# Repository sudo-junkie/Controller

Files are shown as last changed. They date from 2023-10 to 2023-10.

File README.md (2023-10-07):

# Controller

KiCad 7 design files (schematic, PCB, gerber, BOM) for a replacement PCB for the UCOM USB game controller that introduces the following features:
- ESP32 based (WiFi + Bluetooth onboard) with external (IPEX) antenna
- SPI LCD Connector
- Micro SD Card slot 
- Single cell lithium battery charger
- USB C for programming/joystick
- Onboard accelerometer + gyroscope + magnetometer (MPU9250)
- 8 analog inputs (4 pressure-sensitive buttons + 2 joysticks)
- 8 digital inputs
- Toggle switch
- Infrared TX/RX 
- RGB LED

While this board has been designed to be dimensionally identical to the original PCB, a little 'hacking' on the part of the casing to make room for the USB connector, infrared transmitter/receiver and for the mounting of the toggle switch and external ESP32 antenna.

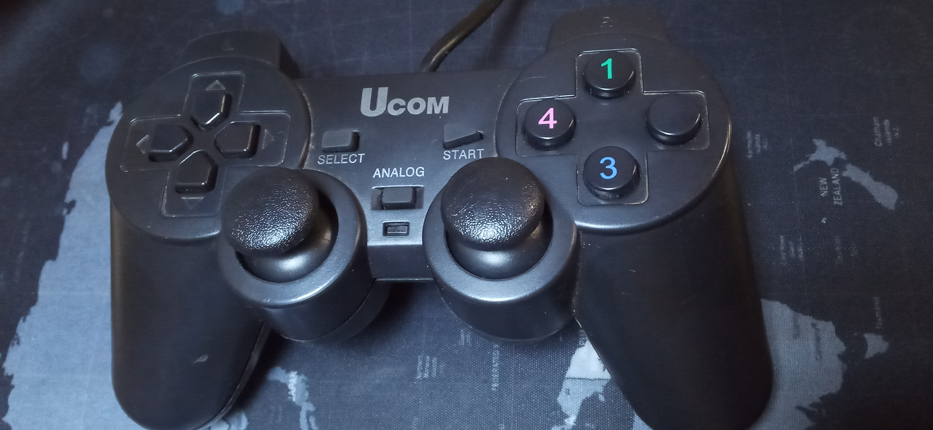
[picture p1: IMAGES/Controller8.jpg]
UCOM Controller


- Original

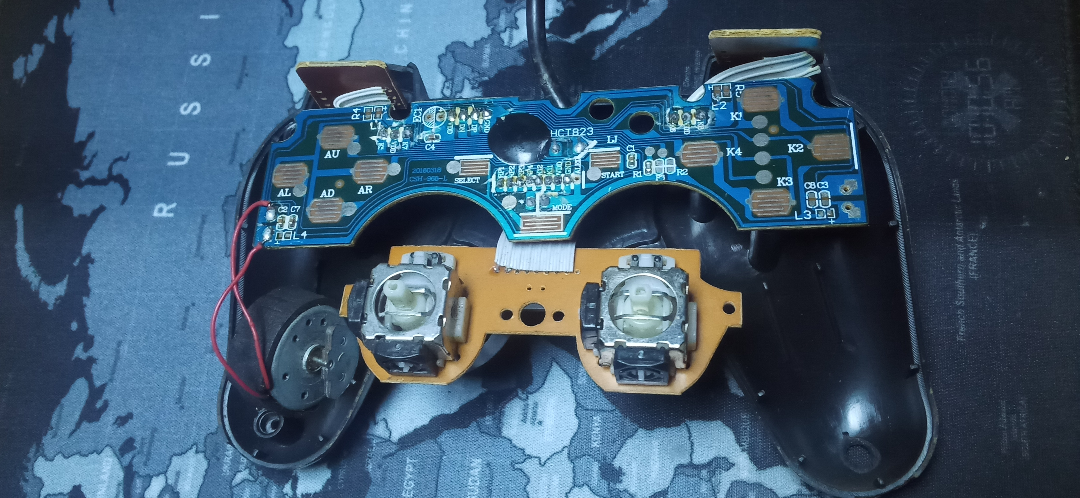
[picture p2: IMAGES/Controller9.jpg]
Controller Top

  
- Upgraded

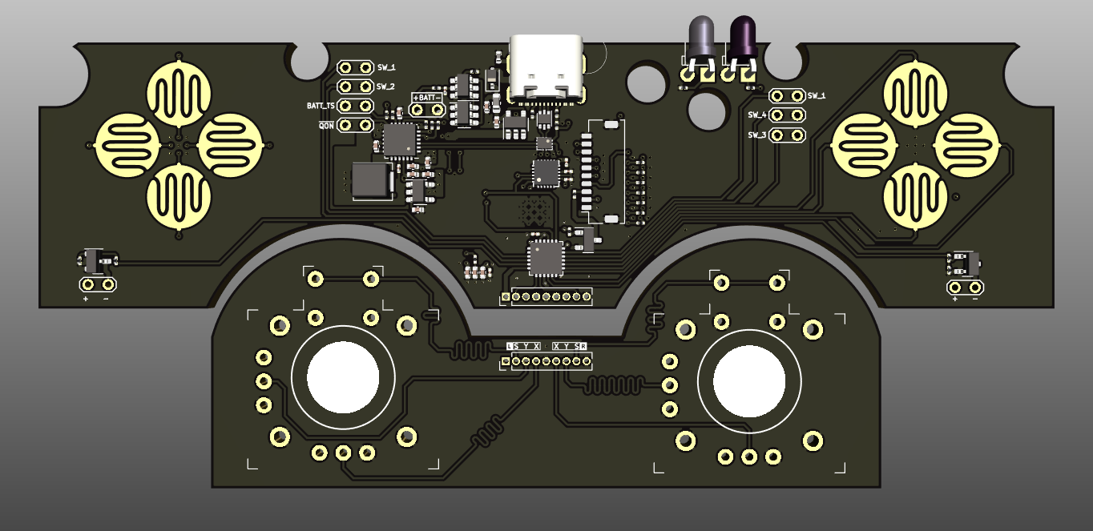
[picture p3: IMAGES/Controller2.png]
Controller Top


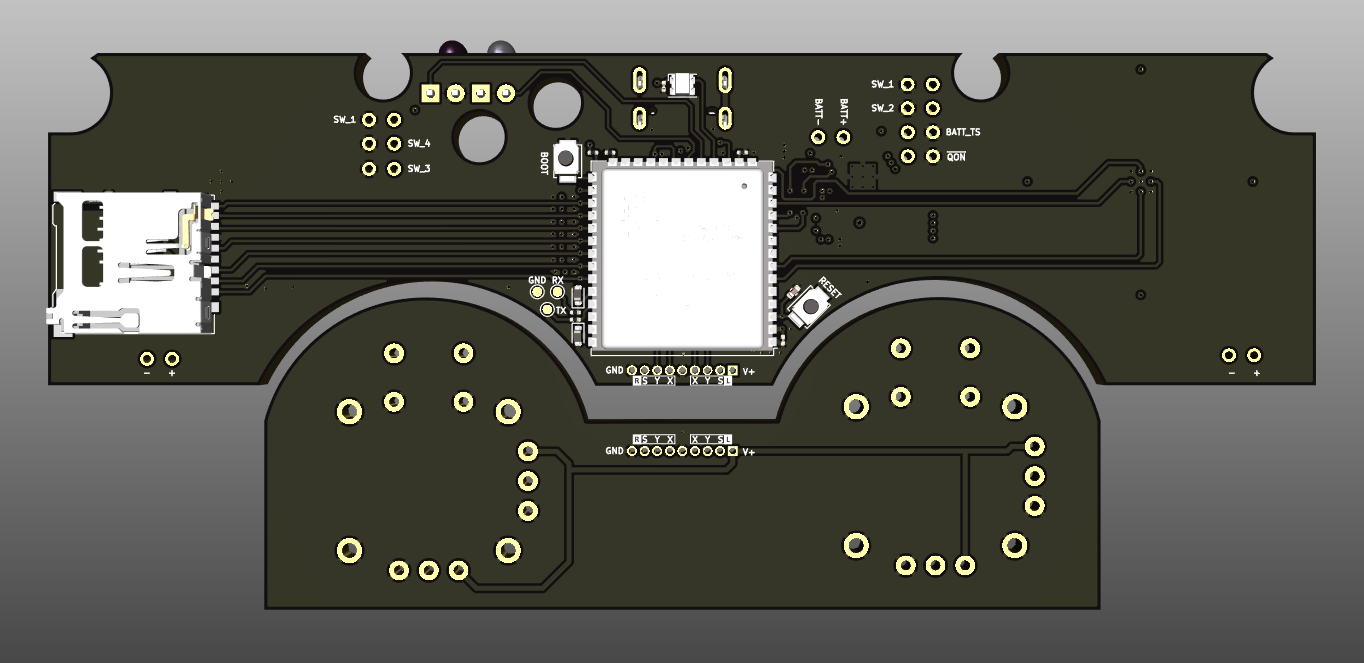
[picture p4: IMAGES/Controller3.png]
Controller Bottom


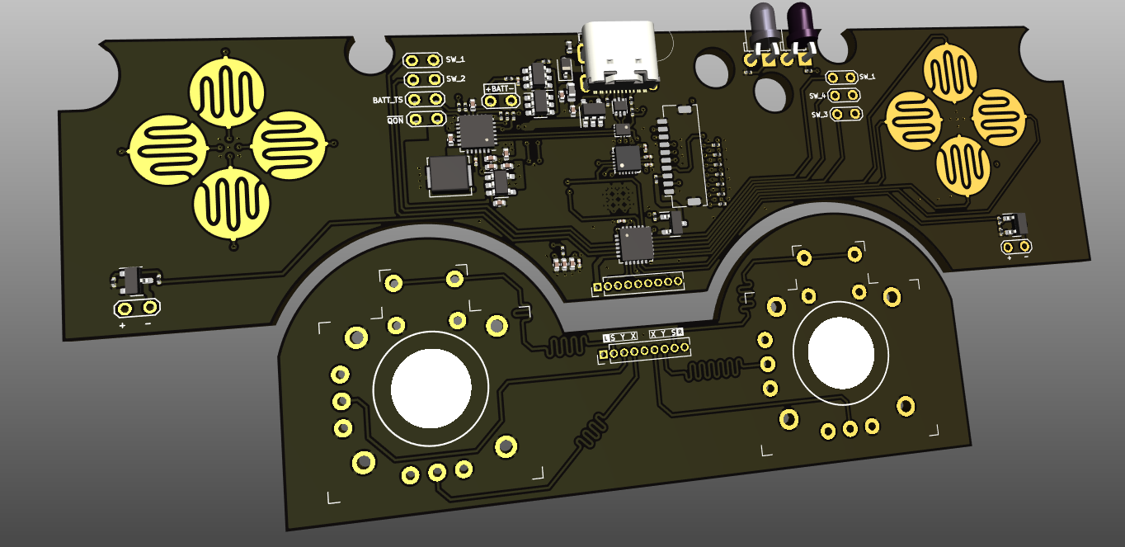
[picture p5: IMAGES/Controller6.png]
Controller Isometric


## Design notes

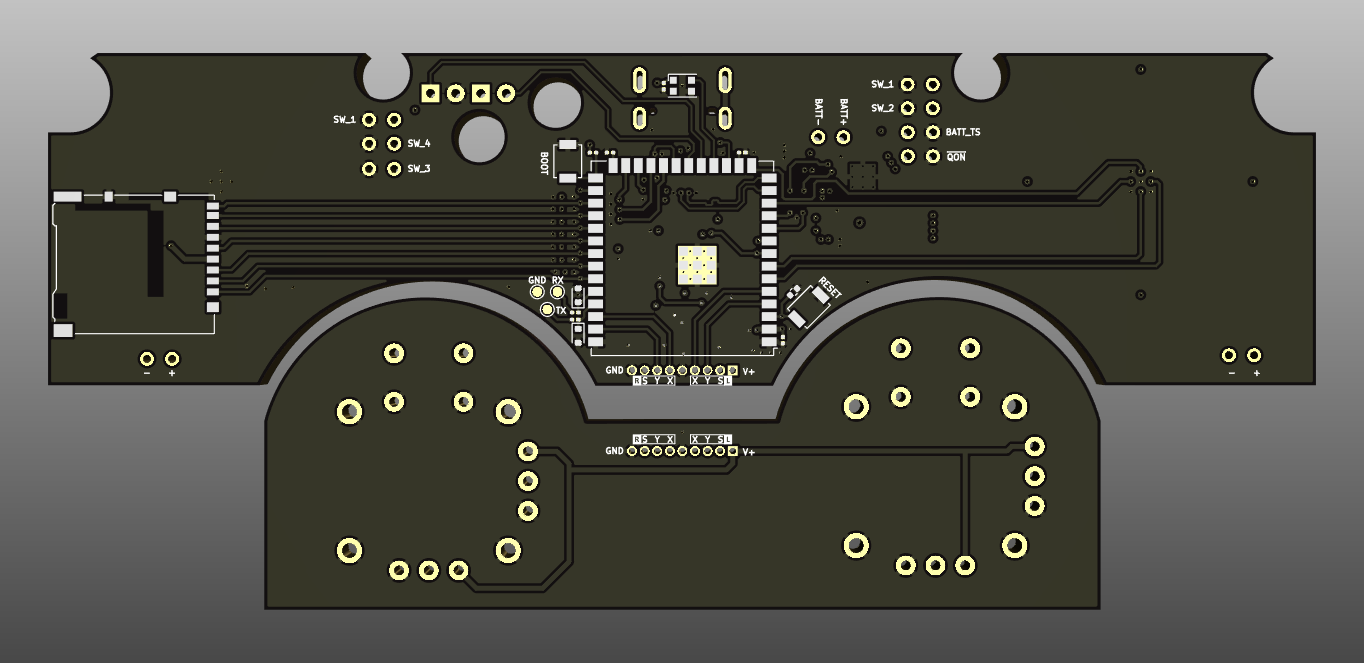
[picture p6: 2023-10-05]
IMAGES/Controller1.png

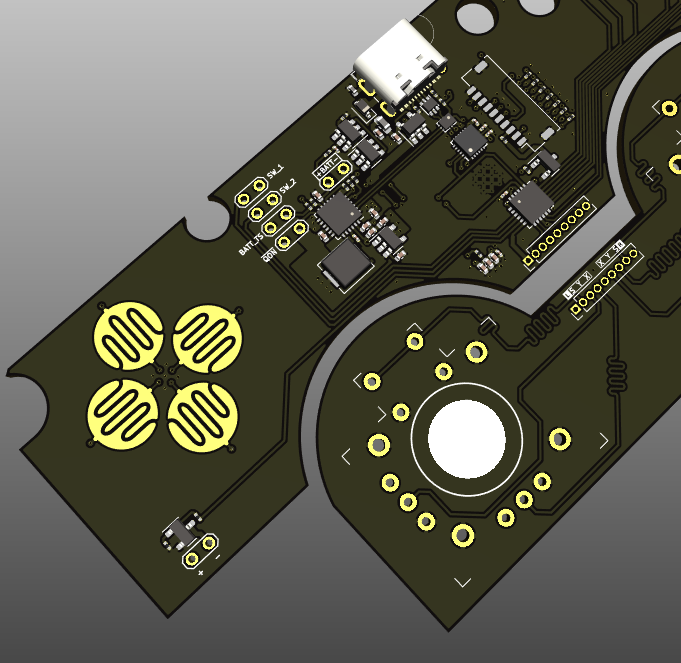
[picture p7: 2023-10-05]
IMAGES/Controller4.png

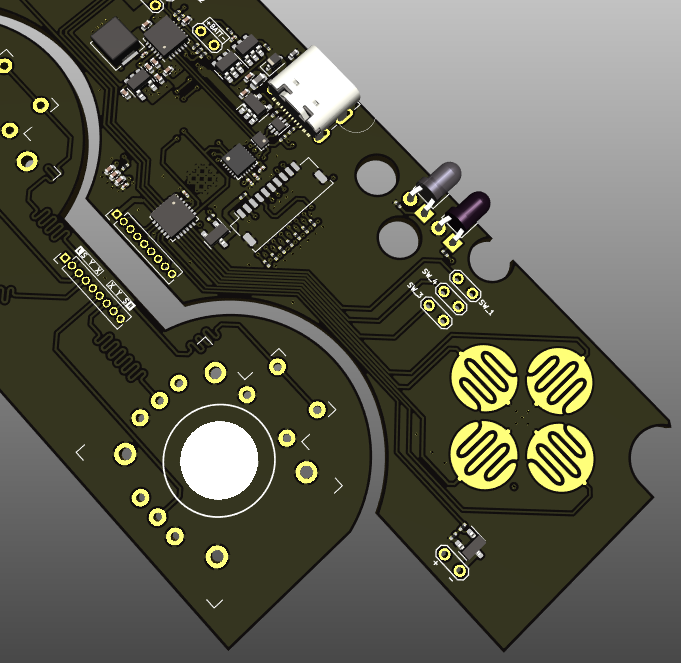
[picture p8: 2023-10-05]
IMAGES/Controller5.png

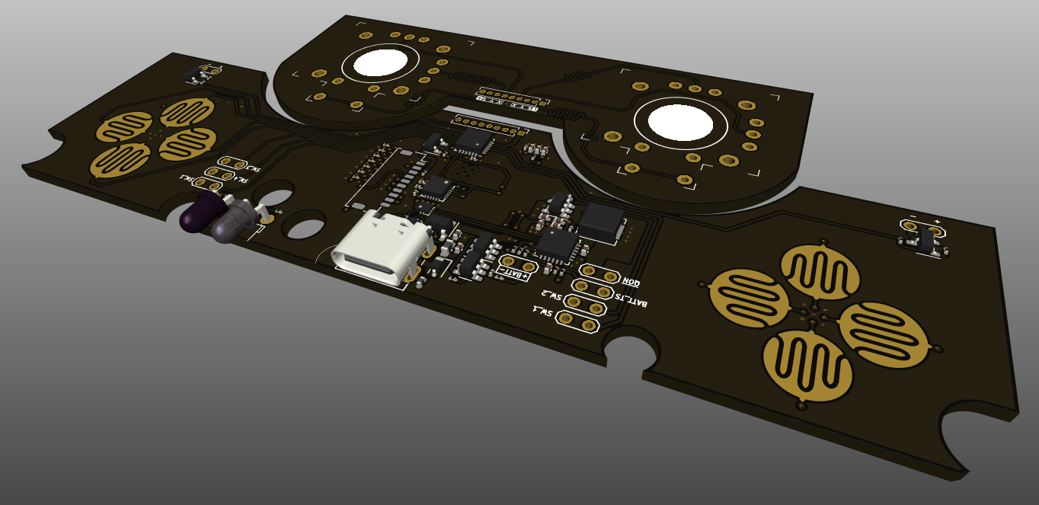
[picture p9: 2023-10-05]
IMAGES/Controller7.png

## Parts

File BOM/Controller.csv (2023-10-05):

Reference | Value | Footprint | JLCPCB # | MANUFACTURER | MPN | UNIT PRICE | VENDOR | Qty
C201, C202, C304, C307, C308, C403, C406 | 1u 10% 10V X5R | Capacitor_SMD:C_0402_1005Metric | C14445 | Samsung Electro-Mechanics | CL05A105KP5NNNC | 0.0019 | LCSC | 7
C301 | 10u 20% 16V X5R | Capacitor_SMD:C_0402_1005Metric | C315248 | Samsung Electro-Mechanics | CL05A106MP5NUNC | 0.0111 | LCSC | 1
C302, C303, C401, C402 | 10u 10% 10V X5R | Capacitor_SMD:C_0402_1005Metric | C962136 | Samsung Electro-Mechanics | CL10A106KO8NQNC | 0.0278 | LCSC | 4
C305 | 4u7 20% 16V X5R | Capacitor_SMD:C_0402_1005Metric | C318563 | Samsung Electro-Mechanics | CL05A475MO5NUNC | 0.0099 | LCSC | 1
C306, C404, C407, C502-C505 | 100n 10% 16V X5R | Capacitor_SMD:C_0201_0603Metric | C307380 | Samsung Electro-Mechanics | CL03A104KO3NNNC | 0.0018 | LCSC | 7
C309 | 47n 10% 16V X5R | Capacitor_SMD:C_0201_0603Metric | C7393833 | CCTC | TCC0201X5R473K160ZT | 0.0009 | LCSC | 1
C405, C501 | 10n 10% 10V X7R | Capacitor_SMD:C_0201_0603Metric | C526939 | YAGEO | CC0201JRX7R7BB103 | 0.0017 | LCSC | 2
D201 | 3A | Diode_SMD:D_SOD-323 | C133103 | STMicroelectronics | BAT60JFILM | 0.1038 | LCSC | 1
D401, D402 | 3V3 | Diode_SMD:D_SOD-523 | C209615 | ROHM Semicon | EDZVT2R3.3B | 0.0167 | LCSC | 2
D403 | WS2812B | LED_SMD:LED_WS2812B-2020_PLCC4_2.0x2.0mm | C5349955 | XINGLIGHT | XL-2020RGBC-WS2812B | 0.072 | LCSC | 1
D501 | IR204A | LED_THT:LED_D3.0mm_Horizontal_O1.27mm_Z2.0mm_IRGrey | C7470790 | TONYU | DY-IR204T-E12 | 0.041 | LCSC | 1
FB201 | 120R@100MHz 3A | Inductor_SMD:L_0603_1608Metric | C353920 | TAI-TECH | HCB1608KF-121T30 | 0.0035 | LCSC | 1
J101 | USB_C_Receptacle_USB2.0 | Connector_USB:USB_C_Receptacle_JAE_DX07S016JA1R1500 | C5187472 | SHOU HAN | TYPE-C 16P QTWT | 0.0662 | LCSC | 1
J501 | Micro_SD_Card | Connector_Card:microSD_HC_Hirose_DM3AT-SF-PEJM5 | C114218 | HRS(Hirose) | DM3AT-SF-PEJM5 | 1.1789 | LCSC | 1
J502 | Conn_LCD | Connector_JST:JST_SHL_SM10B-SHLS-TF_1x10-1MP_P1.00mm_Horizontal | C262716 | JUSHUO | AFA07-S10FCA-00 | 0.1068 | LCSC | 1
L101 | 1u | Inductor_SMD:L_0402_1005Metric | C84468 | Sunlord | SDFL1005Q1R0KTF | 0.0095 | LCSC | 1
L301 | 1u | Inductor_SMD:L_Sunlord_MWSA0402S | C7187305 | DMBJ | CXP0420-1ROM-AG(1uh) | 0.101 | LCSC | 1
Q501-Q503 | MMBT3904 | Package_TO_SOT_SMD:SOT-23 | C5184404 | HXY MOSFET | MMBT3904 | 0.0052 | LCSC | 3
Q504 | Q_Photo_NPN | LED_THT:LED_D3.0mm_Horizontal_O1.27mm_Z2.0mm_IRBlack | C7470722 | TONYU | DY-PT204B-A5 | 0.0477 | LCSC | 1
R201, R305-R308, R403-R406, R501-R507, R512, R513 | 10K 0.5% | Resistor_SMD:R_0201_0603Metric | C319932 | Viking Tech | AR01DTD1002 | 0.0068 | LCSC | 18
R202, R203, R303 | 5K1 0.5% | Resistor_SMD:R_0201_0603Metric | C319556 | Viking Tech | AR01DTD5101 | 0.0224 | LCSC | 3
R301 | 100R | Resistor_SMD:R_0201_0603Metric | C270366 | UNI-ROYAL(Uniroyal Elec) | 0201WMF1000TEE | 0.0007 | LCSC | 1
R302, R508-R511, R514, R515 | 1K | Resistor_SMD:R_0201_0603Metric | C270365 | UNI-ROYAL(Uniroyal Elec) | 0201WMF1001TEE | 0.0007 | LCSC | 7
R304 | 30K9 | Resistor_SMD:R_0201_0603Metric | C364366 | YAGEO | RC0201FR-0730K9L | 0.0004 | LCSC | 1
R401, R402 | 470R | Resistor_SMD:R_0201_0603Metric | C852285 | YAGEO | RT0201DRD07470RL | 0.0447 | LCSC | 2
SW301 | SW_PWR | TestPoint:TestPoint_2Pads_Pitch2.54mm_Drill0.8mm | C231329 | Omron Electronics | B3U-1000P | 0.1729 | LCSC | 1
SW401 | SW_RST | Button_Switch_SMD:SW_SPST_B3U-1000P | C231329 | Omron Electronics | B3U-1000P | 0.1729 | LCSC | 1
SW402 | SW_DWN | Button_Switch_SMD:SW_SPST_B3U-1000P | C231329 | Omron Electronics | B3U-1000P | 0.1729 | LCSC | 1
TH301 | 103AT | TestPoint:TestPoint_2Pads_Pitch2.54mm_Drill0.8mm | C123373 | Nanjing Shiheng Elec | MF52A103J3435 (A1) | 0.0288 | LCSC | 1
U201 | AP2171W | Package_TO_SOT_SMD:SOT-23-5 | C110466 | Diodes Incorporated | AP2171WG-7 | 0.1141 | LCSC | 1
U202 | PI3USB4000AZM | Package_DFN_QFN:UQFN-10_1.4x1.8mm_P0.4mm | C559586 | Diodes Incorporated | PI3USB4000AZMEX | 0.7223 | LCSC | 1
U203 | USBLC6-2P6 | Package_TO_SOT_SMD:SOT-666 | C5199178 | ElecSuper | USBLC6-2P6-ES | 0.0584 | LCSC | 1
U301 | DW01A | Package_TO_SOT_SMD:SOT-23-6 | C351410 | PUOLOP | DW01A | 0.0341 | LCSC | 1
U302 | 8205S | Package_TO_SOT_SMD:SOT-23-6 | C2762930 | JSMSEMI | 8205S | 0.0367 | LCSC | 1
U303 | TLV75733PDBV | Package_TO_SOT_SMD:SOT-23-5 | C485517 | Texas Instruments | TLV75733PDBVR | 0.1877 | LCSC | 1
U304 | BQ25611 | Package_DFN_QFN:WQFN-24-1EP_4x4mm_P0.5mm_EP2.6x2.6mm_ThermalVias | C2892871 | Texas Instruments | BQ25611DRTWR | 1.5735 | LCSC | 1
U401 | ESP32-S3-WROOM-1-N16R8 | RF_Module:ESP32-S3-WROOM-1U | C2980299 | Espressif Systems | ESP32-S3-MINI-1U-N8 | 5.2516 | LCSC | 1
U501 | MPU-9250 | Sensor_Motion:InvenSense_QFN-24_3x3mm_P0.4mm | C71459 | TDK InvenSense | MPU-9250 | 9.9178 | LCSC | 1
U503 | TCA9555RTWR | Package_DFN_QFN:WQFN-24-1EP_4x4mm_P0.5mm_EP2.45x2.45mm | C140277 | Texas Instruments | TCA9555RTWR | 1.4287 | LCSC | 1

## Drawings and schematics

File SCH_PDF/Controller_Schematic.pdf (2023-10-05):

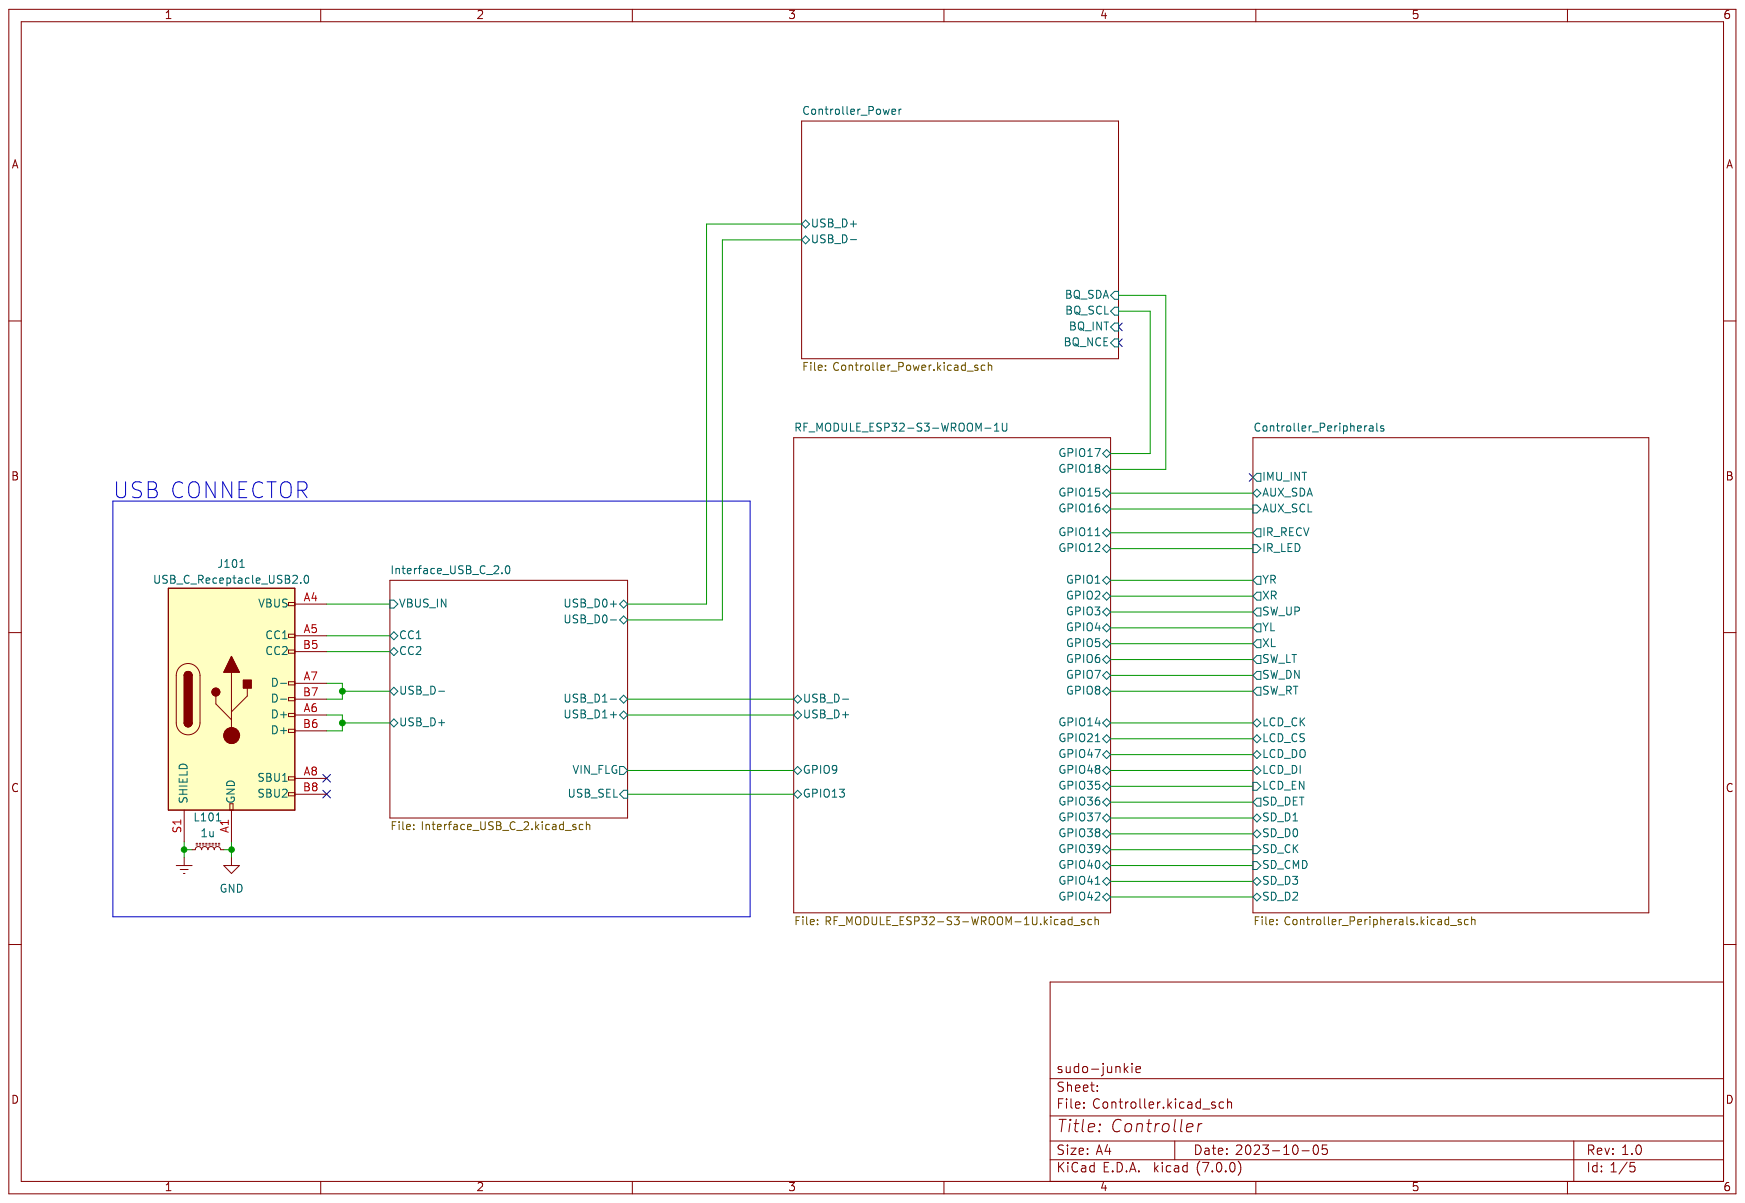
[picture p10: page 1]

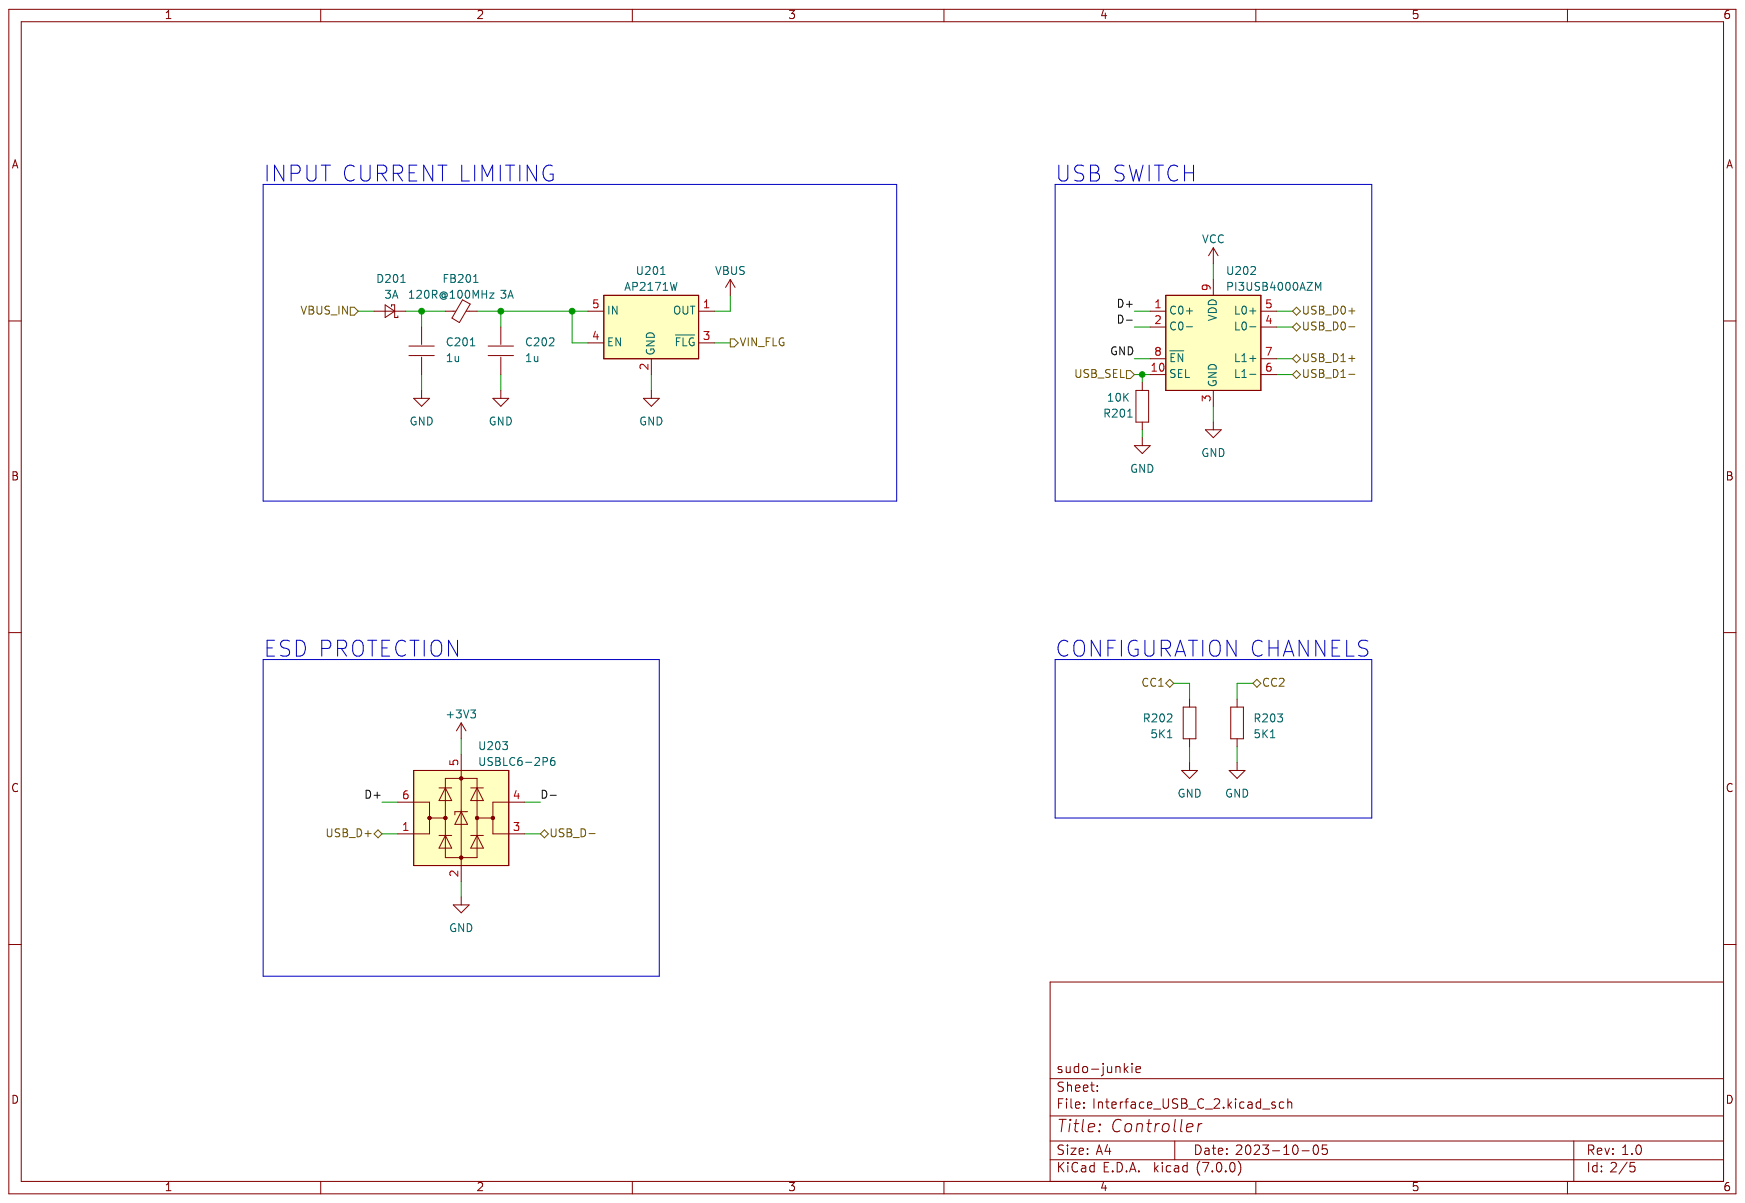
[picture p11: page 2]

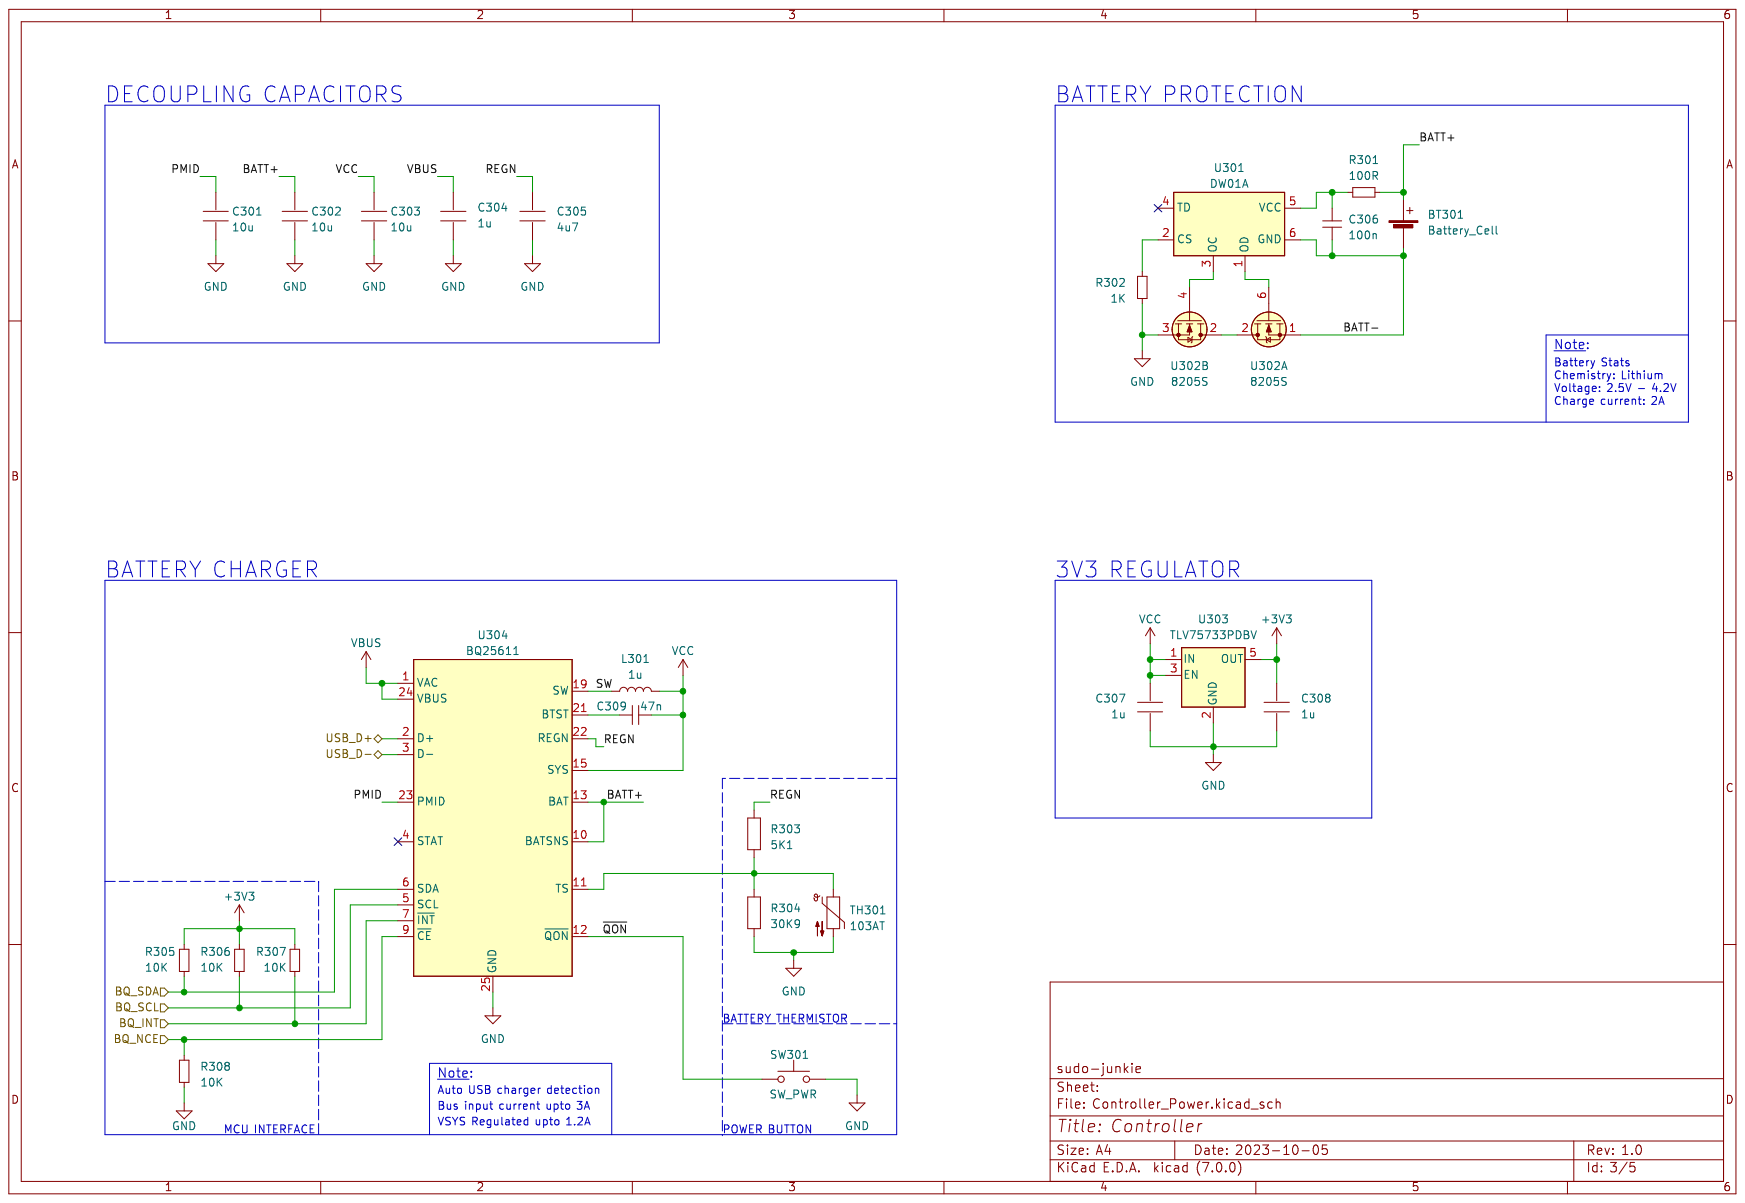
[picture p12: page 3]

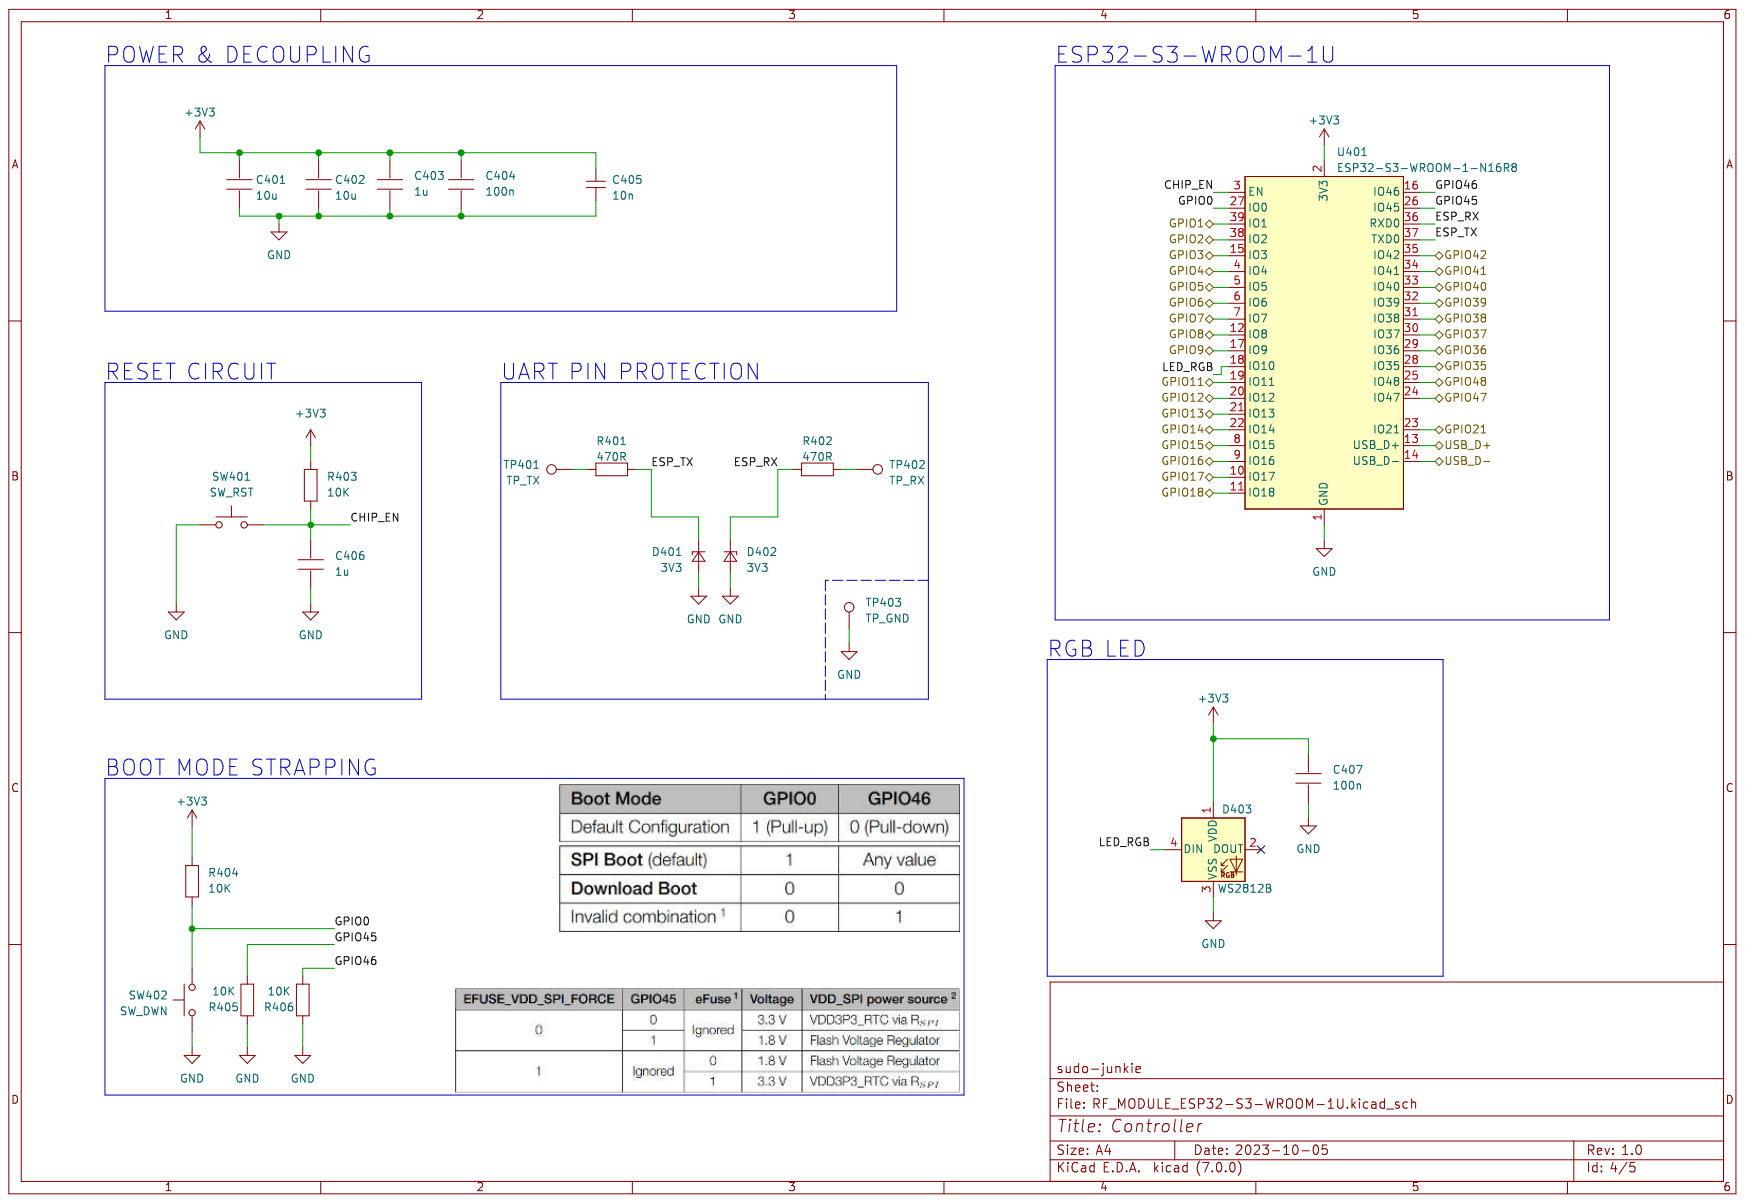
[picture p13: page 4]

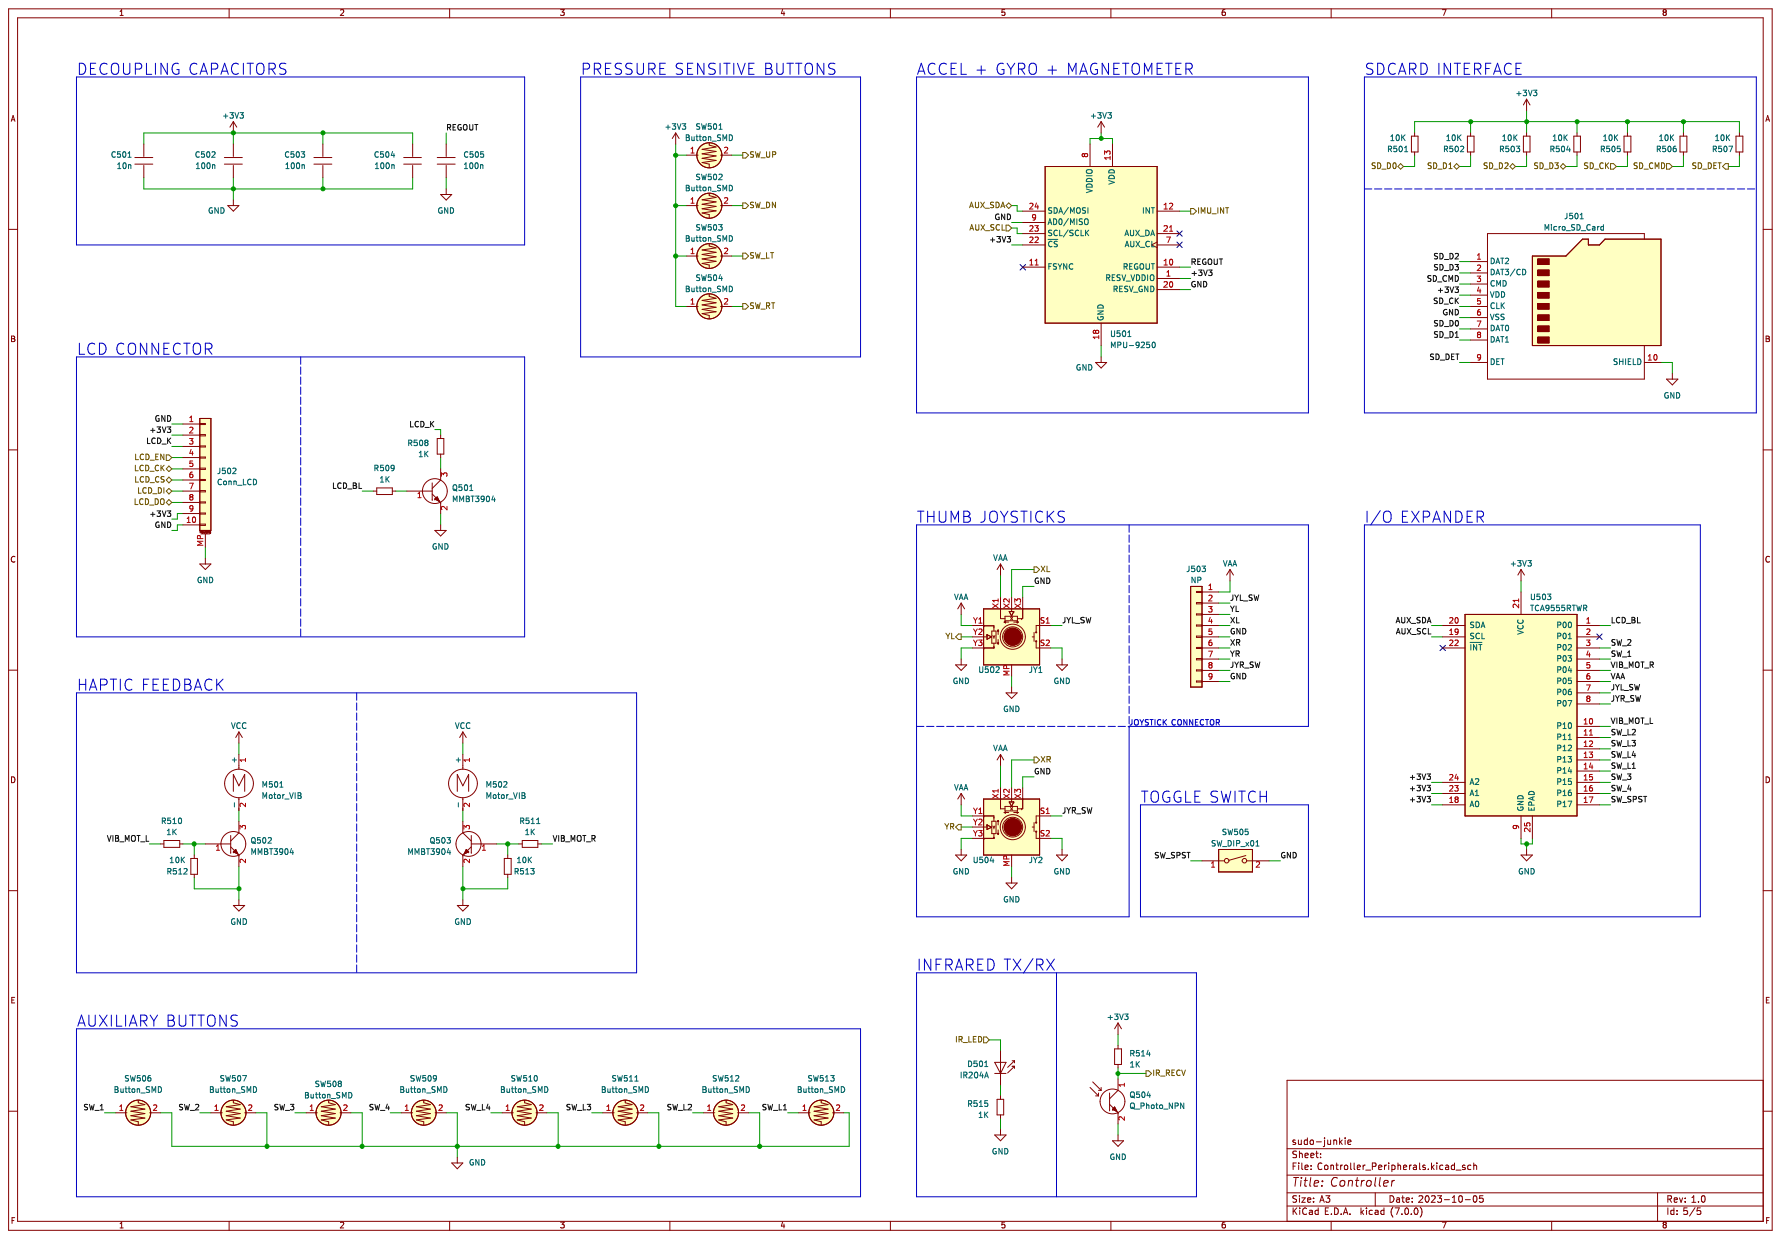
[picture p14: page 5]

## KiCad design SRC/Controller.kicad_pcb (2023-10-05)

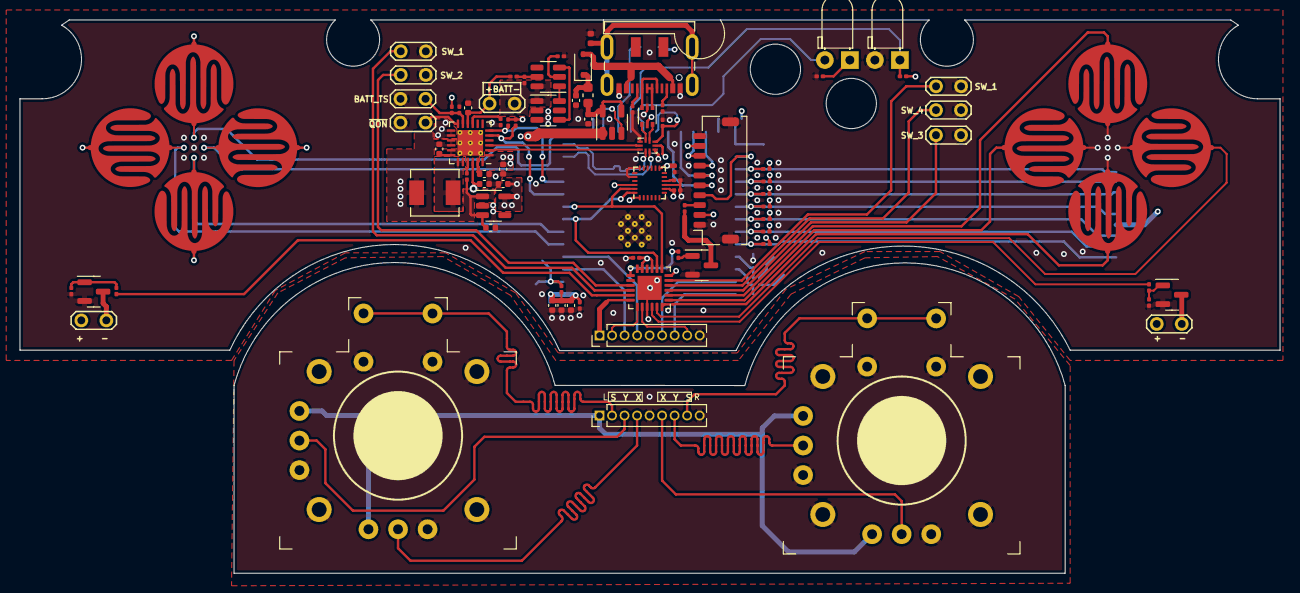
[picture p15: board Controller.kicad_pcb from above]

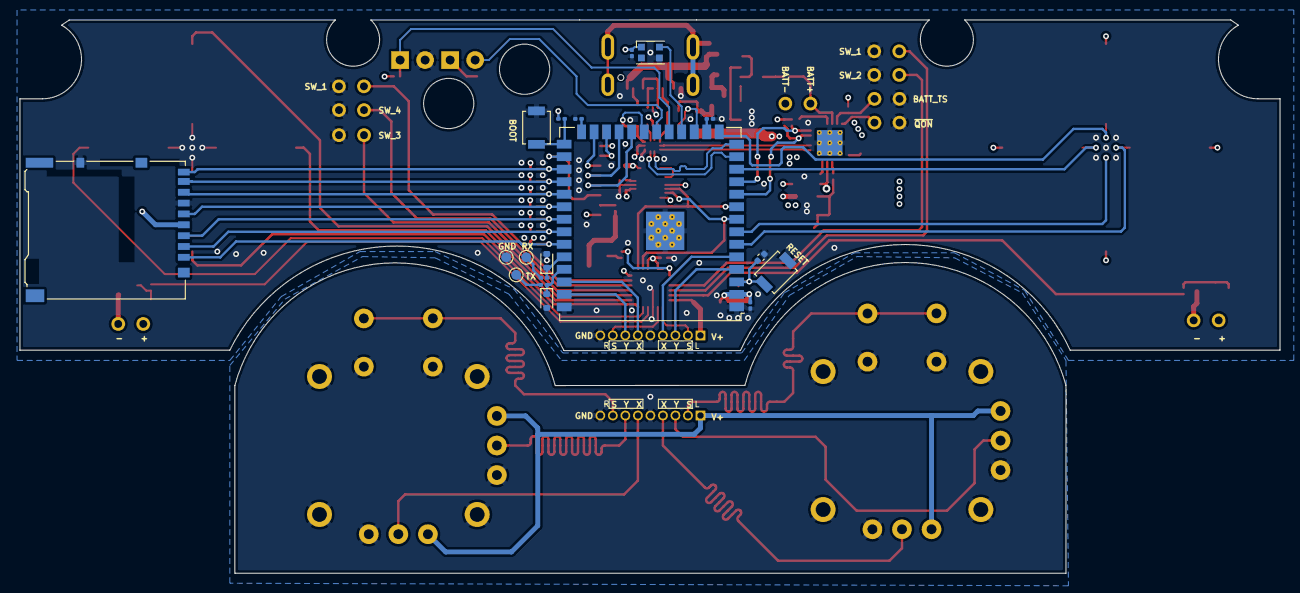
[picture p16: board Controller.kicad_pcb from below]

Board: 4 copper layers, 127.8 x 56.1 mm, 105 parts (18 on the bottom side), 92 nets.

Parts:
BT301: Battery_Cell; TestPoint_2Pads_Pitch2.54mm_Drill0.8mm
C201, C202, C304, C307, C308, C403, C406: 1u; C_0402_1005Metric
C301, C302, C303, C401, C402: 10u; C_0402_1005Metric
C305: 4u7; C_0402_1005Metric
C306, C404, C407, C502, C503, C505: 100n; C_0201_0603Metric
C309: 47n; C_0201_0603Metric
C405, C501: 10n; C_0201_0603Metric
D201: 3A; D_SOD-323
D401, D402: 3V3; D_SOD-523
D403: WS2812B; LED_WS2812B-2020_PLCC4_2.0x2.0mm
D501: IR204A; LED_D3.0mm_Horizontal_O1.27mm_Z2.0mm_IRGrey
FB201: 120R@100MHz 3A; L_0603_1608Metric
J101: USB_C_Receptacle_USB2.0; USB_C_Receptacle_JAE_DX07S016JA1R1500
J501: Micro_SD_Card; microSD_HC_Hirose_DM3AT-SF-PEJM5
J502: Conn_LCD; JST_SHL_SM10B-SHLS-TF_1x10-1MP_P1.00mm_Horizontal
J503, J503#2: NP; PinHeader_1x09_P1.27mm_Vertical
L101: 1u; L_0402_1005Metric
L301: 1u; L_Sunlord_MWSA0402S
M501, M502: Motor_VIB; TestPoint_2Pads_Pitch2.54mm_Drill0.8mm
Q501, Q502, Q503: MMBT3904; SOT-23
Q504: Q_Photo_NPN; LED_D3.0mm_Horizontal_O1.27mm_Z2.0mm_IRBlack
R201, R305, R306, R308, R403, R404, R405, R406, R501, R502, R503, R504, R505, R506, R507, R512, R513: 10K; R_0201_0603Metric
R202, R203, R303: 5K1; R_0201_0603Metric
R301: 100R; R_0201_0603Metric
R302, R508, R509, R510, R511, R514, R515: 1K; R_0201_0603Metric
R304: 30K9; R_0201_0603Metric
R401, R402: 470R; R_0201_0603Metric
SW301: SW_PWR; TestPoint_2Pads_Pitch2.54mm_Drill0.8mm
SW401: SW_RST; SW_SPST_B3U-1000P
SW402: SW_DWN; SW_SPST_B3U-1000P
SW501, SW502, SW503, SW504, SW510, SW511, SW512, SW513: Button_SMD; SMD_BTN
SW505: SW_DIP_x01; TestPoint_2Pads_Pitch2.54mm_Drill0.8mm
SW506, SW507, SW508, SW509: Button_SMD; TestPoint_2Pads_Pitch2.54mm_Drill0.8mm
TH301: 103AT; TestPoint_2Pads_Pitch2.54mm_Drill0.8mm
TP401: TP_TX; TestPoint_Pad_D1.0mm
TP402: TP_RX; TestPoint_Pad_D1.0mm
TP403: TP_GND; TestPoint_Pad_D1.0mm
U201: AP2171W; SOT-23-5
U202: PI3USB4000AZM; UQFN-10_1.4x1.8mm_P0.4mm
U203: USBLC6-2P6; SOT-666
U301: DW01A; SOT-23-6
U302: 8205S; SOT-23-6
U303: TLV75733PDBV; SOT-23-5
U304: BQ25611; WQFN-24-1EP_4x4mm_P0.5mm_EP2.6x2.6mm_ThermalVias
U401: ESP32-S3-WROOM-1-N16R8; ESP32-S3-WROOM-1U
U501: MPU-9250; InvenSense_QFN-24_3x3mm_P0.4mm
U502: JY1; Joystick
U503: TCA9555RTWR; WQFN-24-1EP_4x4mm_P0.5mm_EP2.45x2.45mm
U504: JY2; Joystick

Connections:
+3V3: C308.1, C401.1, C402.1, C403.1, C404.1, C405.1, C407.1, C501.1, C502.1, C503.1, D403.1 (VDD), J501.4 (VDD), J502.2, J502.9, R305.1, R306.1, R403.1, R404.1, R501.2, R502.2, R503.2, R504.2, R505.2, R506.2, R507.2, R514.1, SW501.1, SW502.1, SW503.1, SW504.1, U203.5 (VBUS), U303.5 (OUT), U401.2 (3V3), U501.1 (RESV_VDDIO), U501.8 (VDDIO), U501.13 (VDD), U501.22 (~CS), U503.18 (A0), U503.21 (VCC), U503.23 (A1), U503.24 (A2)
/Controller_Peripherals/AUX_SCL: U401.9 (IO16), U501.23 (SCL/SCLK), U503.19 (SCL)
/Controller_Peripherals/AUX_SDA: U401.8 (IO15), U501.24 (SDA/MOSI), U503.20 (SDA)
/Controller_Peripherals/IR_LED: D501.2 (A), U401.20 (IO12)
/Controller_Peripherals/IR_RECV: Q504.1 (C), R514.2, U401.19 (IO11)
/Controller_Peripherals/JYL_SW: J503.2, J503#2.2, U502.S1, U503.7 (P06)
/Controller_Peripherals/JYR_SW: J503.8, J503#2.8, U503.8 (P07), U504.S1
/Controller_Peripherals/LCD_BL: R509.1, U503.1 (P00)
/Controller_Peripherals/LCD_CK: J502.5, U401.22 (IO14)
/Controller_Peripherals/LCD_CS: J502.6, U401.23 (IO21)
/Controller_Peripherals/LCD_DI: J502.7, U401.25 (IO48)
/Controller_Peripherals/LCD_DO: J502.8, U401.24 (IO47)
/Controller_Peripherals/LCD_EN: J502.4, U401.28 (IO35)
/Controller_Peripherals/LCD_K: J502.3, R508.1
/Controller_Peripherals/REGOUT: C505.1, U501.10 (REGOUT)
/Controller_Peripherals/SD_CK: J501.5 (CLK), R505.1, U401.32 (IO39)
/Controller_Peripherals/SD_CMD: J501.3 (CMD), R506.1, U401.33 (IO40)
/Controller_Peripherals/SD_D0: J501.7 (DAT0), R501.1, U401.31 (IO38)
/Controller_Peripherals/SD_D1: J501.8 (DAT1), R502.1, U401.30 (IO37)
/Controller_Peripherals/SD_D2: J501.1 (DAT2), R503.1, U401.35 (IO42)
/Controller_Peripherals/SD_D3: J501.2 (DAT3/CD), R504.1, U401.34 (IO41)
/Controller_Peripherals/SD_DET: J501.9 (DET), R507.1, U401.29 (IO36)
/Controller_Peripherals/SW_1: SW506.1, U503.4 (P03)
/Controller_Peripherals/SW_2: SW507.1, U503.3 (P02)
/Controller_Peripherals/SW_3: SW508.1, U503.15
/Controller_Peripherals/SW_4: SW509.1, U503.16
/Controller_Peripherals/SW_DN: SW502.2, U401.7 (IO7)
/Controller_Peripherals/SW_L1: SW513.1, U503.14
/Controller_Peripherals/SW_L2: SW512.1, U503.11
/Controller_Peripherals/SW_L3: SW511.1, U503.12
/Controller_Peripherals/SW_L4: SW510.1, U503.13
/Controller_Peripherals/SW_LT: SW503.2, U401.6 (IO6)
/Controller_Peripherals/SW_RT: SW504.2, U401.12 (IO8)
/Controller_Peripherals/SW_SPST: SW505.1, U503.17
/Controller_Peripherals/SW_UP: SW501.2, U401.15 (IO3)
/Controller_Peripherals/VIB_MOT_L: R510.1, U503.10
/Controller_Peripherals/VIB_MOT_R: R511.1, U503.5 (P04)
/Controller_Peripherals/XL: J503.4, J503#2.4, U401.5 (IO5), U502.X2
/Controller_Peripherals/XR: J503.6, J503#2.6, U401.38 (IO2), U504.X2
/Controller_Peripherals/YL: J503.3, J503#2.3, U401.4 (IO4), U502.Y2
/Controller_Peripherals/YR: J503.7, J503#2.7, U401.39 (IO1), U504.Y2
/Controller_Power/BATT+: BT301.1 (+), C302.1, R301.1, U304.10 (BATSNS), U304.13 (BAT), U304.14 (BAT)
/Controller_Power/BATT-: BT301.2 (-), C306.2, U301.6 (GND), U302.1 (S1)
/Controller_Power/BQ_NCE: R308.1, U304.9 (~CE)
/Controller_Power/BQ_SCL: R306.2, U304.5 (SCL), U401.10 (IO17)
/Controller_Power/BQ_SDA: R305.2, U304.6 (SDA), U401.11 (IO18)
/Controller_Power/PMID: C301.1, U304.23 (PMID)
/Controller_Power/REGN: C305.1, R303.1, U304.22 (REGN)
/Controller_Power/SW: L301.1, U304.19 (SW), U304.20 (SW)
/Controller_Power/USB_D+: U202.5 (L0+), U304.2 (D+)
/Controller_Power/USB_D-: U202.4 (L0-), U304.3 (D-)
/Controller_Power/~QON: SW301.1, U304.12 (~QON)
/Interface_USB_C_2.0/CC1: J101.A5 (CC1), R202.1
/Interface_USB_C_2.0/CC2: J101.B5 (CC2), R203.1
/Interface_USB_C_2.0/D+: U202.1 (C0+), U203.6 (I/O1)
/Interface_USB_C_2.0/D-: U202.2 (C0-), U203.4 (I/O2)
/Interface_USB_C_2.0/USB_D1+: U202.7 (L1+), U401.13 (USB_D+)
/Interface_USB_C_2.0/USB_D1-: U202.6 (L1-), U401.14 (USB_D-)
/Interface_USB_C_2.0/USB_D+: J101.A6 (D+), J101.B6 (D+), U203.1 (I/O1)
/Interface_USB_C_2.0/USB_D-: J101.A7 (D-), J101.B7 (D-), U203.3 (I/O2)
/Interface_USB_C_2.0/USB_SEL: R201.2, U202.10 (SEL), U401.21 (IO13)
/Interface_USB_C_2.0/VBUS_IN: D201.2 (A), J101.A4 (VBUS), J101.A9 (VBUS), J101.B4 (VBUS), J101.B9 (VBUS)
/Interface_USB_C_2.0/VIN_FLG: U201.3 (~FLG), U401.17 (IO9)
/RF_MODULE_ESP32-S3-WROOM-1U/CHIP_EN: C406.1, R403.2, SW401.2, U401.3 (EN)
/RF_MODULE_ESP32-S3-WROOM-1U/ESP_RX: D402.1 (K), R402.1, U401.36 (RXD0)
/RF_MODULE_ESP32-S3-WROOM-1U/ESP_TX: D401.1 (K), R401.2, U401.37 (TXD0)
/RF_MODULE_ESP32-S3-WROOM-1U/GPIO0: R404.2, SW402.1, U401.27 (IO0)
/RF_MODULE_ESP32-S3-WROOM-1U/GPIO45: R405.2, U401.26 (IO45)
/RF_MODULE_ESP32-S3-WROOM-1U/GPIO46: R406.2, U401.16 (IO46)
/RF_MODULE_ESP32-S3-WROOM-1U/LED_RGB: D403.4 (DIN), U401.18 (IO10)
Earth: J101.S1 (SHIELD), L101.1
GND: C201.2, C202.2, C301.2, C302.2, C303.2, C304.2, C305.2, C307.2, C308.2, C401.2, C402.2, C403.2, C404.2, C405.2, C406.2, C407.2, C501.2, C502.2, C503.2, C505.2, D401.2 (A), D402.2 (A), D403.3 (VSS), J101.A1 (GND), J101.A12 (GND), J101.B1 (GND), J101.B12 (GND), J501.6 (VSS), J501.10 (SHIELD), J502.1, J502.10, J502.MP (MountPin), J503.5, J503.9, J503#2.5, J503#2.9, L101.2, Q501.2 (E), Q502.2 (E), Q503.2 (E), Q504.2 (E), R201.1, R202.2, R203.2, R302.2, R304.2, R308.2, R405.1, R406.1, R512.1, R513.1, R515.2, SW301.2, SW401.1, SW402.2, SW505.2, SW506.2, SW507.2, SW508.2, SW509.2, SW510.2, SW511.2, SW512.2, SW513.2, TH301.2, TP403.1, U201.2 (GND), U202.3 (GND), U202.8 (~EN), U203.2 (GND), U302.3 (S2), U303.2 (GND), U304.17 (GND), U304.18 (GND), U304.25 (GND), U401.1 (GND), U401.40 (GND), U401.41 (GND), U501.9 (AD0/MISO), U501.18 (GND), U501.20 (RESV_GND), U502.MP, U502.S2, U502.X3, U502.Y3, U503.9 (GND), U503.25 (EPAD), U504.MP, U504.S2, U504.X3, U504.Y3
unnamed: C201.1, D201.1 (K), FB201.1
unnamed: D501.1 (K), R515.1
unnamed: M501.2 (-), Q502.3 (C)
unnamed: M502.2 (-), Q503.3 (C)
unnamed: Q501.1 (B), R509.2
unnamed: Q501.3 (C), R508.2
unnamed: Q502.1 (B), R510.2, R512.2
unnamed: Q503.1 (B), R511.2, R513.2
unnamed: R401.1, TP401.1
unnamed: R402.2, TP402.1
unnamed: C202.1, FB201.2, U201.4 (EN), U201.5 (IN)
unnamed: R302.1, U301.2 (CS)
unnamed: U301.3 (OC), U302.4 (G2)
unnamed: U301.1 (OD), U302.6 (G1)
unnamed: C306.1, R301.2, U301.5 (VCC)
unnamed: C309.1, U304.21 (BTST)
unnamed: R303.2, R304.1, TH301.1, U304.11 (TS)
VAA: J503.1, J503#2.1, U502.X1, U502.Y1, U503.6 (P05), U504.X1, U504.Y1
VBUS: C304.1, U201.1 (OUT), U304.1 (VAC), U304.24 (VBUS)
VCC: C303.1, C307.1, C309.2, L301.2, M501.1 (+), M502.1 (+), U202.9 (VDD), U303.1 (IN), U303.3 (EN), U304.15 (SYS), U304.16 (SYS)
